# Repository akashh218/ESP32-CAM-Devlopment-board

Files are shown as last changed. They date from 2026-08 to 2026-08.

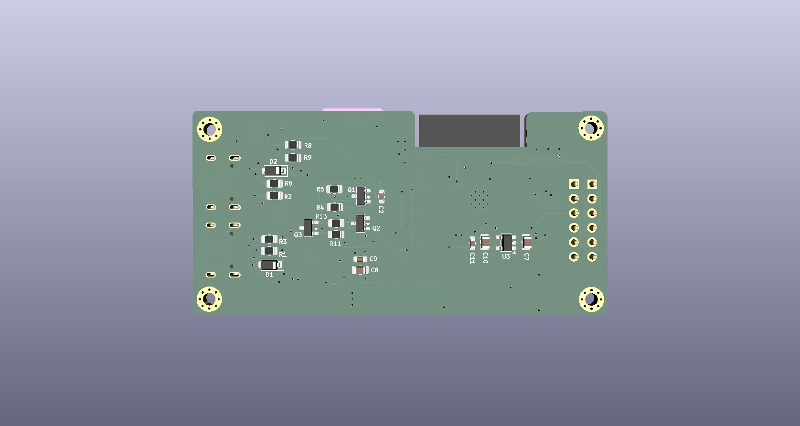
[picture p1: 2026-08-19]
esp32_cam/esp32_cam_back.png

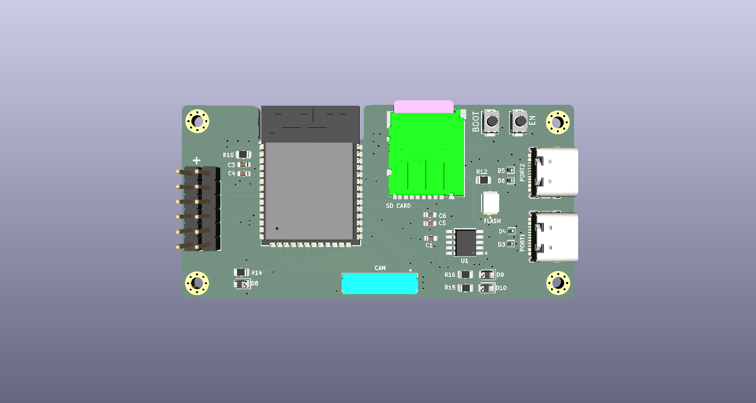
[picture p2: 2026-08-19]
esp32_cam/esp32_cam_front.png

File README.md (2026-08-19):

# ESP32-S3 Camera Development Board

A custom **4-layer ESP32-S3 camera development board** designed in **KiCad**, with a focus on compact PCB layout, signal integrity, power integrity, grounding, and practical embedded hardware development.

## Overview

This project involves the complete design of a compact ESP32-S3-based development board, from schematic design and component selection through PCB placement, routing, and DRC verification.

The board is designed to provide camera capture, local data storage, USB connectivity, serial debugging, GPIO expansion, and camera flash control in a compact form factor.

## Key Features

* Camera interface for image capture
* microSD interface for local image and data storage
* USB-C connectivity for programming and native USB communication
* UART-based serial debugging
* Automatic BOOT and RESET control
* Software-controlled camera flash
* GPIO expansion for external peripherals
* 3.3 V regulated power supply
* Local power decoupling and filtering
* Dedicated ground plane
* Ground stitching vias
* RF-aware ESP32 antenna keep-out
* Compact 4-layer PCB architecture

## PCB Design Approach

The PCB was designed with particular attention to:

* Component placement and functional grouping
* Camera signal routing
* USB differential-pair routing
* microSD signal routing
* Power distribution
* Grounding and return-current paths
* Decoupling capacitor placement
* Antenna clearance
* Via placement and ground stitching
* Manufacturing clearances
* DRC verification

GPIO assignments were also planned to simplify routing and reduce unnecessary trace crossings.

## Layer Stack-up

| Layer | Purpose |
| --- | --- |
| **L1 – Top** | Components and critical signal routing |
| **L2 – GND** | Continuous ground plane |
| **L3 – Power / Signals** | Power distribution and secondary signal routing |
| **L4 – Bottom** | General signal routing and passive components |

The dedicated ground plane provides a continuous reference for signal return paths and helps improve power and signal integrity.

## Design Challenges

Some of the main challenges during development included:

* Routing multiple camera signals within a compact PCB area
* Maintaining clean USB differential-pair routing
* Optimizing GPIO assignments for easier routing
* Managing power and ground distribution
* Maintaining the ESP32 antenna keep-out region
* Resolving PCB design-rule and footprint issues
* Balancing component density with manufacturability

## Tools

* **KiCad** – Schematic capture and PCB design
* **KiCad DRC** – Design-rule verification

## Repository Contents

This repository contains the design files associated with the project, including:

* Schematic files
* PCB layout files
* Footprints and libraries used by the design
* Design documentation
* Manufacturing files, if included

## Project Status

**PCB Design Completed**

The next stage is hardware fabrication and board bring-up, followed by testing of the power system, USB/UART programming, camera interface, microSD storage, and other peripherals.

## Learning Outcomes

This project strengthened my practical understanding of:

* PCB layout and routing
* Embedded hardware design
* Signal integrity
* Power integrity
* Grounding and return paths
* USB/UART interfaces
* RF-aware PCB design
* Component and footprint selection
* DRC debugging
* PCB manufacturability

---

**Designed in KiCad | ESP32-S3 | 4-Layer PCB **

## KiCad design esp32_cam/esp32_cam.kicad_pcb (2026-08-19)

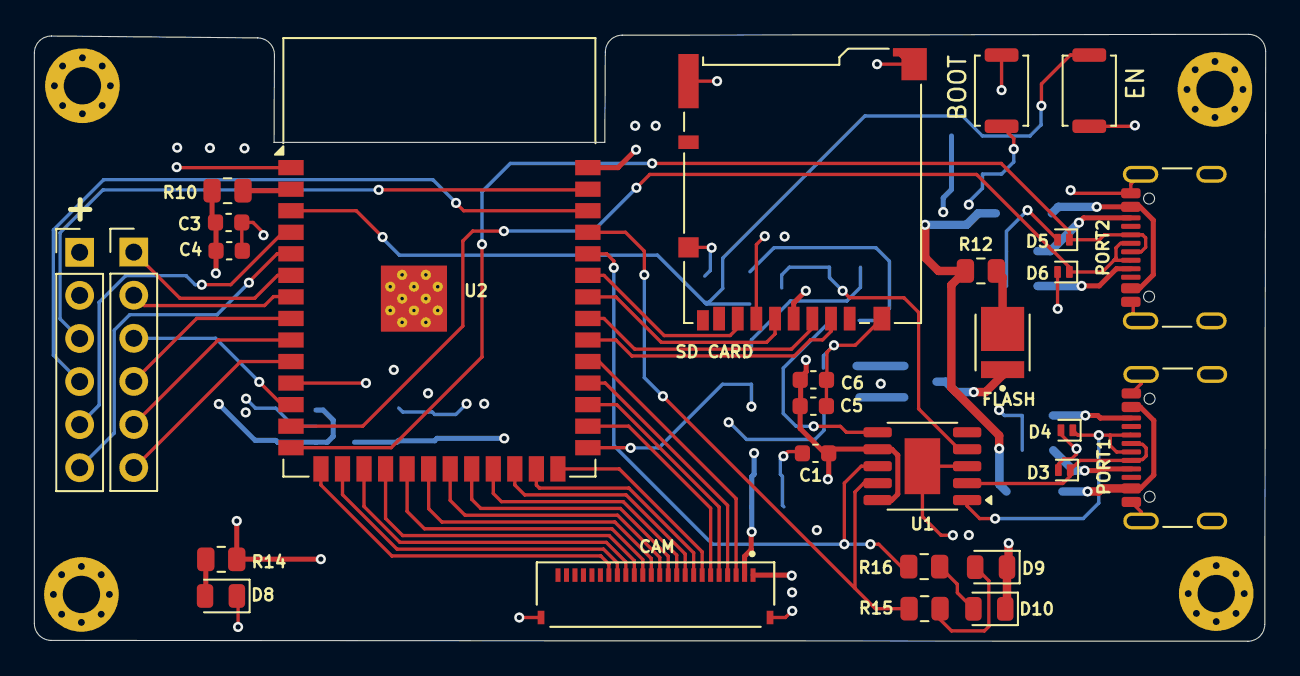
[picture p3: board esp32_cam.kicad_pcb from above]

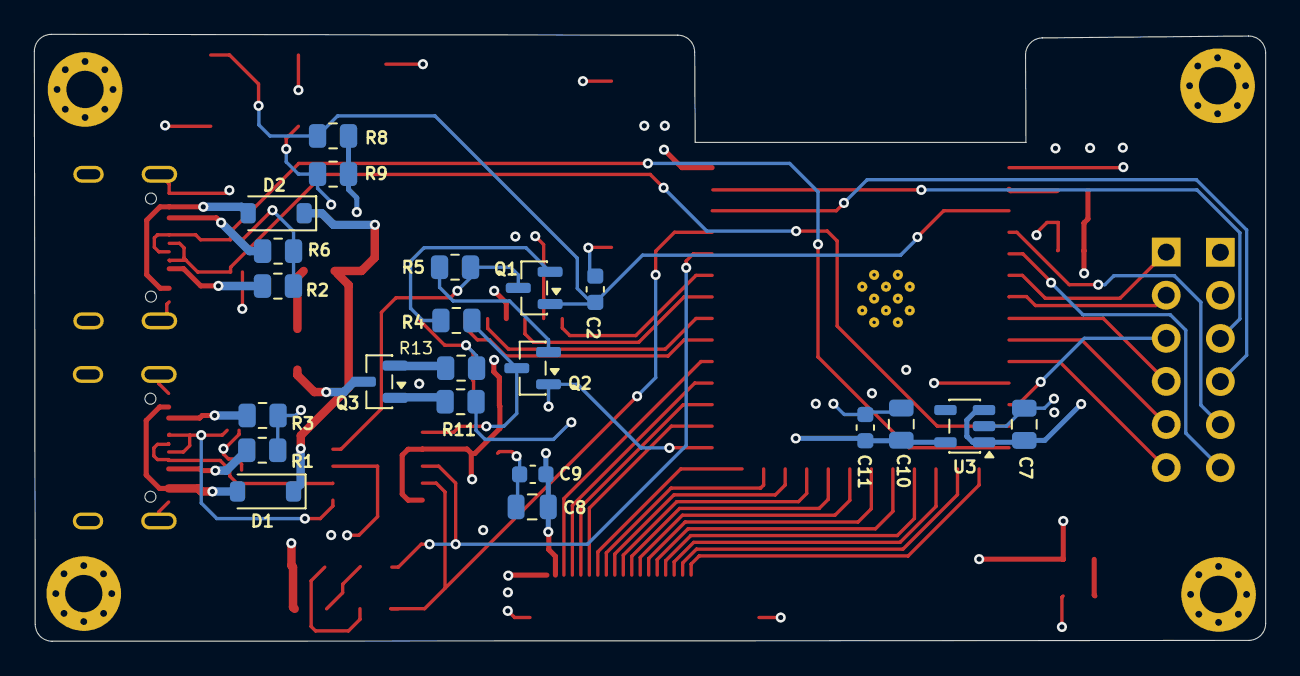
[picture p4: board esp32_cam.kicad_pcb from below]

Board: 4 copper layers, 72.6 x 35.8 mm, 50 parts (22 on the bottom side), 60 nets.

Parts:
BOOT: SW_Push; SW_Push_SPST_NO_Alps_SKRK
C1, C2, C3, C11: 0.1µF; C_0603_1608Metric
C4, C5: 10uF; C_0603_1608Metric
C6, C9: 100nF; C_0603_1608Metric
C7, C8, C10: 10uF; C_0805_2012Metric
CAM: FH34SRJ-24S-0.5SH_99_; HRS_FH34SRJ-24S-0.5SH_99_
D1, D2: D_Schottky; D_SOD-123
D3, D4, D5, D6: PESD5V0L1UL; D_SOD-882
D8, D9, D10: LED; D_0805_2012Metric
EN: SW_Push; SW_Push_SPST_NO_Alps_SKRK
FLASH: OF-SMD2835Y; LED_OF-SMD2835Y
J5, J6: Conn_01x06_Socket; PinHeader_1x06_P2.54mm_Vertical
PORT1, PORT2: USB_C_Receptacle_USB2.0_16P; USB_C_Receptacle_GCT_USB4105-xx-A_16P_TopMnt_Horizontal
Q1, Q2: NPN; SOT-23
Q3: AO3400A; SOT-23
R1, R2, R3, R6: 5.1K; R_0805_2012Metric
R4, R5, R8, R9, R13, R14: 10K; R_0805_2012Metric
R10: 0E; R_0805_2012Metric
R11: 100Ω; R_0805_2012Metric
R12: 68Ω; R_0805_2012Metric
R15, R16: 470Ω; R_0805_2012Metric
SD CARD: Micro_SD_Card; microSD_HC_Hirose_DM3BT-DSF-PEJS
U1: CH340K; SSOP-10-1EP_3.9x4.9mm_P1mm_EP2.1x3.3mm
U2: ESP32-S3-WROOM-1
U3: AP2112K-3.3; SOT-23-5

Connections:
+3.3V: C1.1, C3.1, C4.1, C5.1, C6.1, C8.2, C9.2, C10.1, C11.1, CAM.2, R8.1, R9.1, R10.2, R14.2, SD CARD.4 (VDD), U1.7 (VCC), U1.10 (V3), U3.5 (VOUT)
+5V: C7.1, D1.1 (K), D2.1 (K), J5.1, R12.1, U3.1 (VIN), U3.3 (EN)
/ESP_SECTION/BOOT: BOOT.1, Q2.1 (C), R9.2, U2.27 (IO0)
/ESP_SECTION/D+: D4.1 (K), PORT1.A6 (D+), PORT1.B6 (D+), U1.1 (UD+)
/ESP_SECTION/D-: D3.1 (K), PORT1.A7 (D-), PORT1.B7 (D-), U1.2 (UD-)
/ESP_SECTION/DTR: Q1.3 (E), R5.1, U1.4 (~DTR)
/ESP_SECTION/EN: C2.1, EN.1, Q1.1 (C), R8.2, U2.3 (EN)
/ESP_SECTION/ESP_VCC: R10.1, U2.2 (3V3)
/ESP_SECTION/RTS: Q2.3 (E), R4.1, U1.6 (~RTS)
/ESP_SECTION/USB D+: D5.1 (K), PORT2.A6 (D+), PORT2.B6 (D+), U2.14 (USB_D+)
/ESP_SECTION/USB D-: D6.1 (K), PORT2.A7 (D-), PORT2.B7 (D-), U2.13 (USB_D-)
CAM_RST: CAM.17, U2.16 (IO46)
CLK: SD CARD.5 (CLK), U2.34 (IO41)
CMD: SD CARD.3 (CMD), U2.33 (IO40)
D0: CAM.16, U2.17 (IO9)
D1: CAM.15, U2.18 (IO10)
D2: CAM.14, U2.19 (IO11)
D3: CAM.13, U2.20 (IO12)
D4: CAM.12, U2.21 (IO13)
D5: CAM.11, U2.22 (IO14)
D6: CAM.10, U2.23 (IO21)
D7: CAM.9, U2.24 (IO47)
DAT0: SD CARD.7 (DAT0), U2.35 (IO42)
DAT3: SD CARD.2 (DAT3/CD), U2.32 (IO39)
FLASH_LED: R11.2, U2.11 (IO18)
GND: BOOT.2, C1.2, C2.2, C3.2, C4.2, C5.2, C6.2, C7.2, C8.1, C9.1, C10.2, C11.2, CAM.1, CAM.S1 (SHIELD), CAM.S2 (SHIELD), D3.2 (A), D4.2 (A), D5.2 (A), D6.2 (A), D8.1 (K), D9.1 (K), D10.1 (K), EN.2, J5.2, PORT1.A1 (GND), PORT1.A12 (GND), PORT1.B1 (GND), PORT1.B12 (GND), PORT1.SH (SHIELD), PORT2.A1 (GND), PORT2.A12 (GND), PORT2.B1 (GND), PORT2.B12 (GND), PORT2.SH (SHIELD), R1.2, R2.2, R3.2, R6.2, R13.1, SD CARD.6 (VSS), SD CARD.SH (SHIELD), U1.3 (GND), U1.11 (GND), U2.1 (GND), U2.40 (GND), U2.41 (GND), U3.2 (GND)
HREF: CAM.6, U2.28 (IO35)
IO1: J5.3, U2.39 (IO1)
IO2: J5.4, U2.38 (IO2)
IO4: J5.5, U2.4 (IO4)
IO5: J5.6, U2.5 (IO5)
IO6: J6.1, U2.6 (IO6)
IO7: J6.2, U2.7 (IO7)
IO8: J6.3, U2.12 (IO8)
IO15: J6.4, U2.8 (IO15)
IO16: J6.5, U2.9 (IO16)
IO17: J6.6, U2.10 (IO17)
unnamed: D1.2 (A), PORT1.A4 (VBUS), PORT1.A9 (VBUS), PORT1.B4 (VBUS), PORT1.B9 (VBUS)
unnamed: D2.2 (A), PORT2.A4 (VBUS), PORT2.A9 (VBUS), PORT2.B4 (VBUS), PORT2.B9 (VBUS)
unnamed: FLASH.A, R12.2
unnamed: D8.2 (A), R14.1
unnamed: D9.2 (A), R15.2
unnamed: D10.2 (A), R16.2
unnamed: PORT1.A5 (CC1), R1.1
unnamed: PORT1.B5 (CC2), R3.1
unnamed: PORT2.A5 (CC1), R2.1
unnamed: PORT2.B5 (CC2), R6.1
unnamed: Q1.2 (B), R4.2
unnamed: Q2.2 (B), R5.2
unnamed: FLASH.C, Q3.3 (D)
unnamed: Q3.1 (G), R11.1
unnamed: Q3.2 (S), R13.2
PCLK: CAM.7, U2.26 (IO45)
PWDN: CAM.18, U2.15 (IO3)
RXD0: R16.1, U1.8 (TXD), U2.36 (RXD0)
SCL_CAM: CAM.4, U2.30 (IO37)
SDA_CAM: CAM.3, U2.31 (IO38)
TXD0: R15.1, U1.9 (RXD), U2.37 (TXD0)
VSYNC: CAM.5, U2.29 (IO36)
XCLK: CAM.8, U2.25 (IO48)
